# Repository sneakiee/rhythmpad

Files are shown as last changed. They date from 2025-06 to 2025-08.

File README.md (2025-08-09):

# rhythmpad



This was a YSWS project for Hack Club's hackpad for hack club's highway! I got the idea of creating a hackpad for rhythm games, but I also wanted to generalize it more for music, so I decided to make it into a drum-pad by creating square keycaps! The switches are mapped to the numpad from 1-9 and the extra button on the right being 0. This was my first actual hardware project and I hope to build more because it was a frustrating fun (I need to feel more of that.

# Schematic and PCB
pcb schematic
pcb
3dpcb

# CAD
bottomcase
plate
midcase
3d model

# Components
- 10x cherry mx switches
- 10x through-hole 1N4148 diodes
- 6x SK6812 MINI-E LEDs (unfortunately doesn't work with original files, but if SK6812MINI footprint in KiCad is changed, will work!)
- 1x seeeed XIAO RP2040
- 10x custom 3D printed keycaps
- custom 3D printed top case
- custom 3D printed middle case
- custom 3D printed bottom case
- 4x M3x16 Bolt
- 4x M3 Heatset

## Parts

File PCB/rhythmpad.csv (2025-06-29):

Id | Designator | Footprint | Quantity | Designation | Supplier and ref
1 | D16,D15,D14,D13,D11,D12 | LED_SK6812MINI_PLCC4_3.5x3.5mm_P1.75mm | 6 | SK6812MINI
2 | D3,D8,D4,D9,D2,D6,D7,D1,D5,D10 | D_DO-35_SOD27_P7.62mm_Horizontal | 10 | D
3 | SW5,SW10,SW9,SW3,SW1,SW8,SW4,SW7,SW6,SW2 | SW_Cherry_MX_1.00u_PCB | 10 | SW_Push
4 | U1 | XIAO-RP2040-DIP | 1 | XIAO-RP2040-DIP

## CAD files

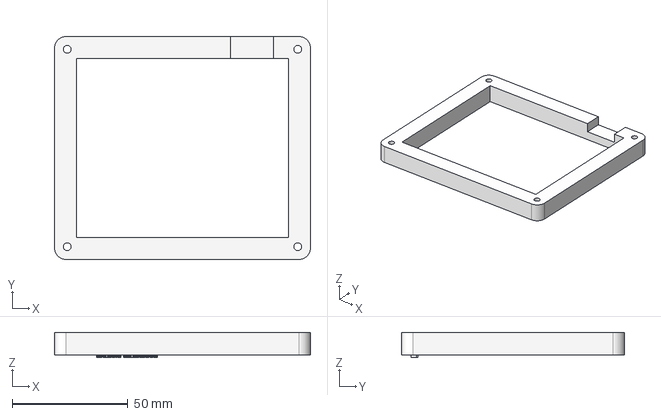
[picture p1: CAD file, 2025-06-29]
production/middle.step
110.5 x 96.2 x 11.0 mm

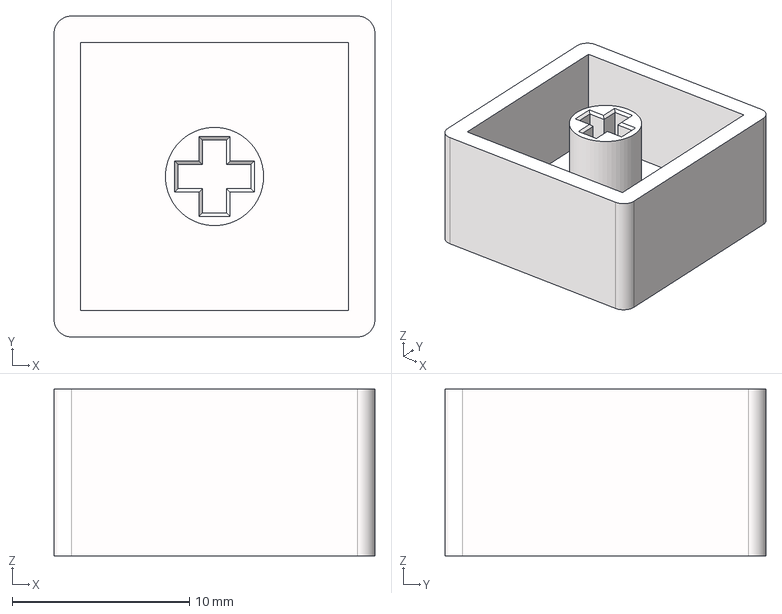
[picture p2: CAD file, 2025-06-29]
production/keycap.step
18.1 x 18.1 x 9.39 mm

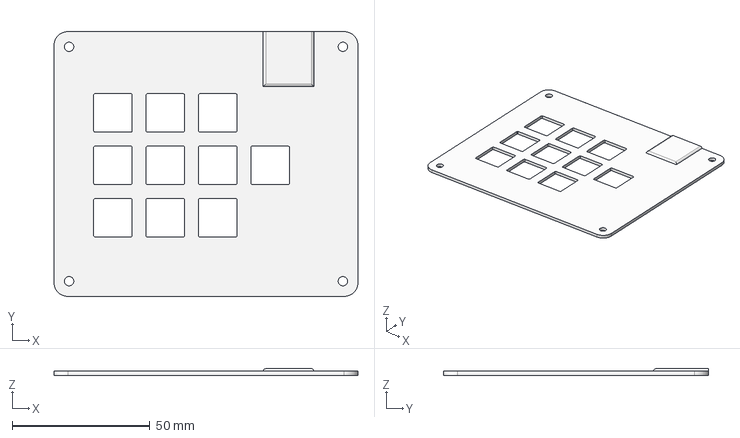
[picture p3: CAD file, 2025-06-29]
production/top.step
110.5 x 96.2 x 2.40 mm

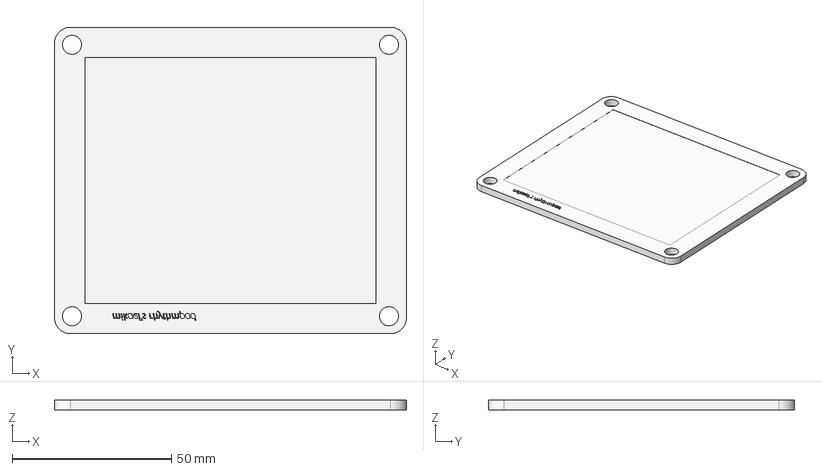
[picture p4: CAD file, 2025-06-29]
production/bottom.step
110.5 x 96.2 x 3.10 mm

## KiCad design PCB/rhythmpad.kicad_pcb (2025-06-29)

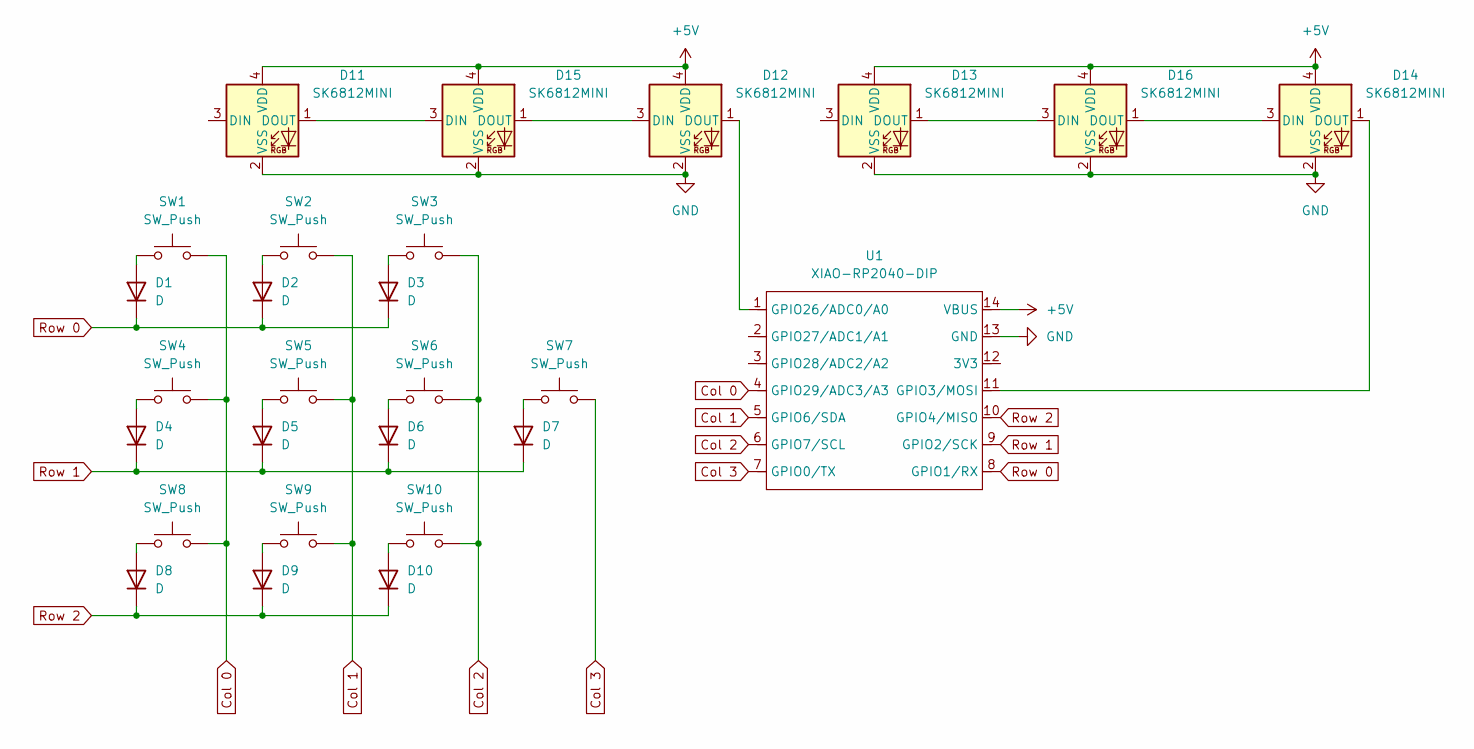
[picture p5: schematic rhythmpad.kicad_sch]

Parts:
D1, D2, D3, D4, D5, D6, D7, D8, D9, D10: D; D_DO-35_SOD27_P7.62mm_Horizontal
D11, D12, D13, D14, D15, D16: SK6812MINI; LED_SK6812MINI_PLCC4_3.5x3.5mm_P1.75mm
SW1, SW2, SW3, SW4, SW5, SW6, SW7, SW8, SW9, SW10: SW_Push; SW_Cherry_MX_1.00u_PCB
U1: XIAO-RP2040-DIP

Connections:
+5V: D11.4 (VDD), D12.4 (VDD), D13.4 (VDD), D14.4 (VDD), D15.4 (VDD), D16.4 (VDD), U1.14 (VBUS)
Col 0: SW1.2, SW4.2, SW8.2, U1.4 (GPIO29/ADC3/A3)
Col 1: SW2.2, SW5.2, SW9.2, U1.5 (GPIO6/SDA)
Col 2: SW3.2, SW6.2, SW10.2, U1.6 (GPIO7/SCL)
Col 3: SW7.2, U1.7 (GPIO0/TX)
GND: D11.2 (VSS), D12.2 (VSS), D13.2 (VSS), D14.2 (VSS), D15.2 (VSS), D16.2 (VSS), U1.13 (GND)
unnamed: D1.2 (A), SW1.1
unnamed: D2.2 (A), SW2.1
unnamed: D3.2 (A), SW3.1
unnamed: D4.2 (A), SW4.1
unnamed: D5.2 (A), SW5.1
unnamed: D6.2 (A), SW6.1
unnamed: D7.2 (A), SW7.1
unnamed: D8.2 (A), SW8.1
unnamed: D9.2 (A), SW9.1
unnamed: D10.2 (A), SW10.1
unnamed: D11.1 (DOUT), D15.3 (DIN)
unnamed: D12.3 (DIN), D15.1 (DOUT)
unnamed: D12.1 (DOUT), U1.1 (GPIO26/ADC0/A0)
unnamed: D13.1 (DOUT), D16.3 (DIN)
unnamed: D14.3 (DIN), D16.1 (DOUT)
unnamed: D14.1 (DOUT), U1.11 (GPIO3/MOSI)
Row 0: D1.1 (K), D2.1 (K), D3.1 (K), U1.8 (GPIO1/RX)
Row 1: D4.1 (K), D5.1 (K), D6.1 (K), D7.1 (K), U1.9 (GPIO2/SCK)
Row 2: D8.1 (K), D9.1 (K), D10.1 (K), U1.10 (GPIO4/MISO)

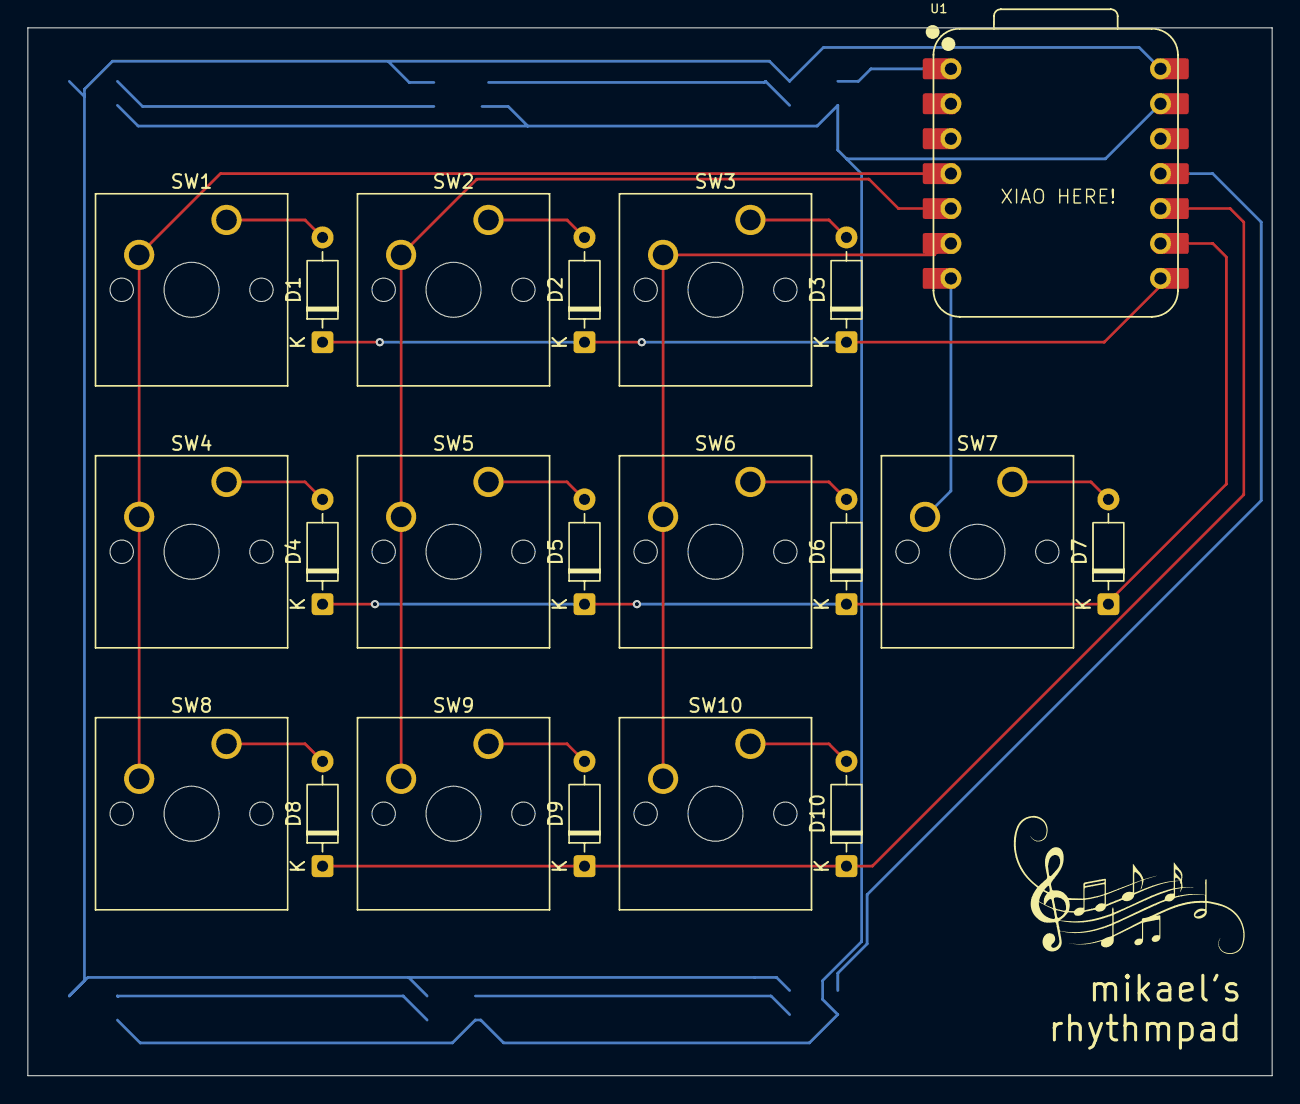
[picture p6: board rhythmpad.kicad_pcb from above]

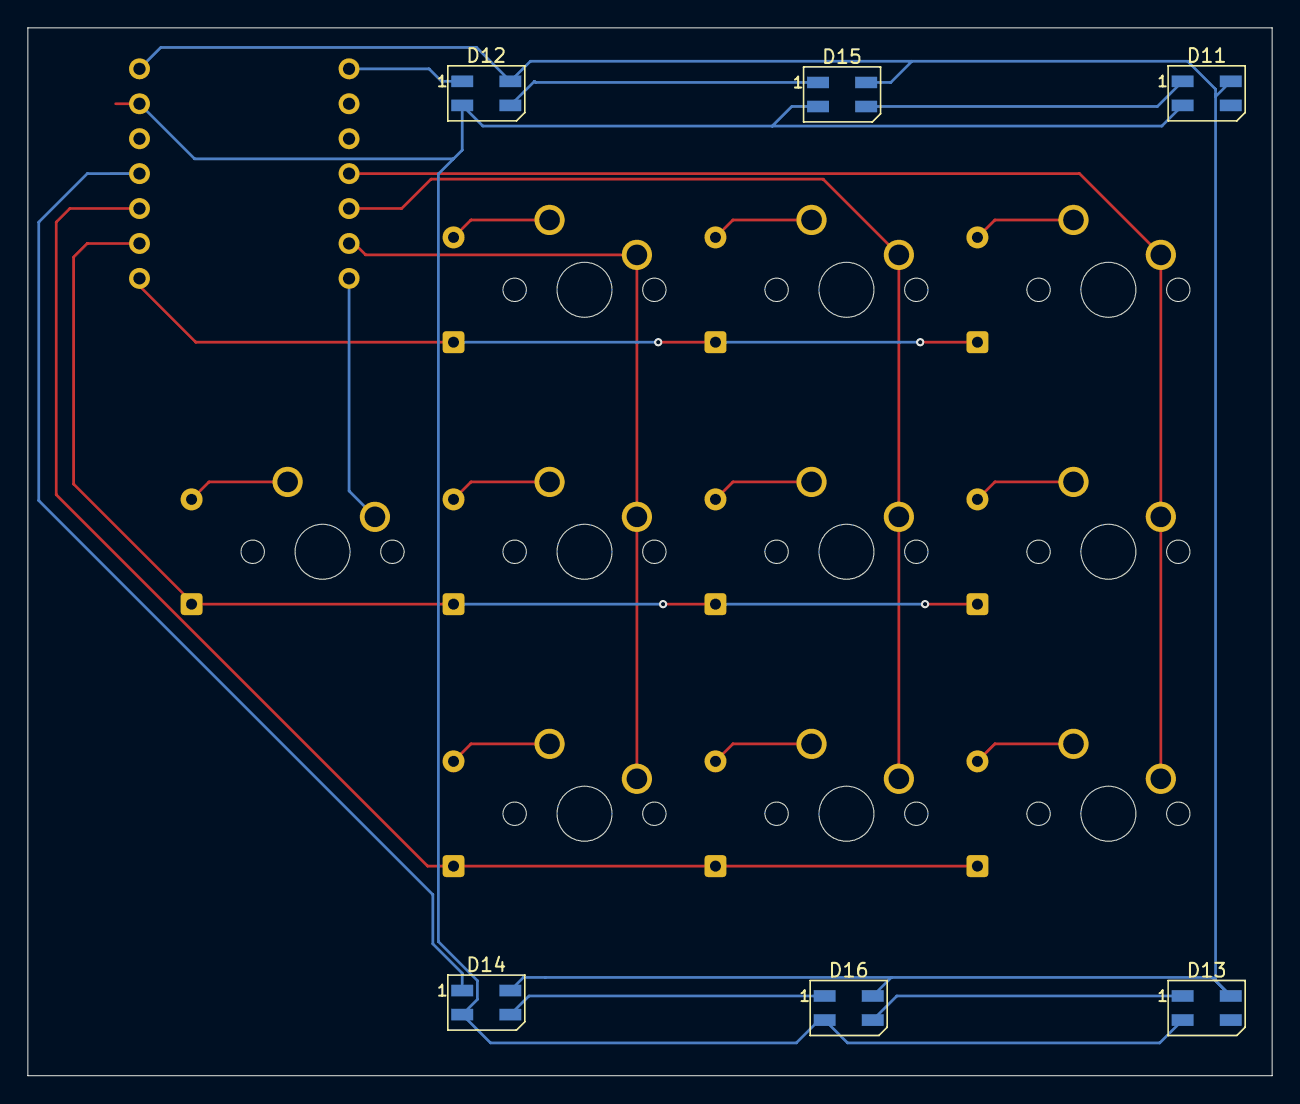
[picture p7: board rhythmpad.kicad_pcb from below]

Board: 2 copper layers, 90.5 x 76.2 mm, 27 parts (6 on the bottom side), 25 nets.

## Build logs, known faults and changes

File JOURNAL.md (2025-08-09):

---
title: "rhythmpad"
author: "Mikael Gomez"
description: "macropad for all rhythm needs (game, drumpad, etc.)"
created_at: "2025-06-11"
---

# June 11th: finished switch matrix & connections 

figured out how to use KiCad! took me a little to understand what was what and a lot of googling to understand PCB structure, but I think I have it down enough LOL

journalentry1

**Total time spent: 2h**

# June 25th: added leds & wired pcb

added some leds and completed the wiring for my pcb :D
i genuinely took so long because it was hard to find a reference and i accidentally had the wrong footprint for my micro controller D:

journalentry2

**Total time spent: 3h**

# June 26th: learning cad :sob:

i wanted to use onshape and ended up having to google too much. lesson learned, be smart and actually look for a tutorial instead of just doing it.
what is wrong wit meee (finishing case incoming)

journalentry3

**Total time spent: 1h**

# June 28th: most productive day!!

locked in and decided to finish everything! i took so long trying to fix problems and never thought of creative ways so i took very very long,
but then i added more leds, created my own keycaps, wrote my firmware, and finished my case! this took too long.... :sob:

3d model

**Total time spent: 5h**

# July 27th-29th: building the thing!

i got all my parts + my soldering iron and was ready to finally build this thing! my main problem was the RP2040 as it was pretty difficult to solder something so small as a beginner hardware maker.. i ended up having to redo with a whole other board, even breaking 2 pins of the xiao in the process... whoops...



its okay though! i somehow desoldered it and learned how to solder decently and then all i needed to do was to solder the LEDS!



i had built my hackpad, and all i really needed to do was change the pins in my firmware! (which took a few minutes but we had it going)



i also recorded some gameplay! https://youtu.be/_harP569IKI

**Total time spent: 2h**

# August 8th: shipping day!

guess what... **unfortunately** the SK6812MINI footprints on KiCad are WRONG!!! (i am a victim...) so unfortunately i am not able to use my LEDS...

i literally spent so long trying to debug my newest firmware just to figure out the footprints are just wrong and i can't solder my LEDs or else the LED will literally just be facing downwards and into the pcb. makes me mad but i still really like how it turned out!




**Total time spent: 2h** (mostly debugging </3)

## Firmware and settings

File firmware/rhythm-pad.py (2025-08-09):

import board

from kmk.kmk_keyboard import KMKKeyboard
from kmk.scanners import DiodeOrientation
from kmk.keys import KC

keyboard = KMKKeyboard()

keyboard.col_pins = [board.A3, board.D4, board.D5, board.D6]
keyboard.row_pins = [board.D7, board.D8, board.D9]
keyboard.diode_orientation = DiodeOrientation.COL2ROW

keyboard.keymap = [
        [
        KC.N7, KC.N8, KC.N9, KC.NO,
        KC.N4, KC.N5, KC.N6, KC.N0,
        KC.N1, KC.N2, KC.N3, KC.NO,
    ]
]

if __name__ == '__main__':
    keyboard.go()

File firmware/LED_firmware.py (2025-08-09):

import board
import neopixel
import time

from kmk.kmk_keyboard import KMKKeyboard
from kmk.scanners import DiodeOrientation
from kmk.keys import KC

keyboard = KMKKeyboard()

keyboard.col_pins = [board.A3, board.D4, board.D5, board.D6]
keyboard.row_pins = [board.D7, board.D8, board.D9]
keyboard.diode_orientation = DiodeOrientation.COL2ROW

LED_TOP_PIN = board.A0
LED_BOTTOM_PIN = board.D10
TOP_LEDS = 3
BOTTOM_LEDS = 3

strip_top = neopixel.NeoPixel(LED_TOP_PIN, TOP_LEDS, brightness=1.0, auto_write=False, pixel_order=(1, 0, 2))
strip_bottom = neopixel.NeoPixel(LED_BOTTOM_PIN, BOTTOM_LEDS, brightness=1.0, auto_write=False, pixel_order=(1, 0, 2))

FIXED_COLOR = (255, 255, 255)
FADE_TIME = 0.5

led_map = {
    0: ([0], []),
    1: ([1], []),
    2: ([2], []),
    3: ([0], [0]),
    4: ([1], [1]),
    5: ([2], [2]),
    6: ([2], [2]),
    7: ([], [0]),
    8: ([], [1]),
    9: ([], [2]),
}

active_keys = {}

def update_leds():
    now = time.monotonic()

    # Clear LEDs
    for i in range(TOP_LEDS):
        strip_top[i] = (0, 0, 0)
    for i in range(BOTTOM_LEDS):
        strip_bottom[i] = (0, 0, 0)

    keys_to_remove = []
    for key_index, press_time in active_keys.items():
        elapsed = now - press_time
        if elapsed >= FADE_TIME:
            keys_to_remove.append(key_index)
            continue

        brightness = 1 - (elapsed / FADE_TIME)
        color = tuple(int(c * brightness) for c in FIXED_COLOR)

        top_idxs, bottom_idxs = led_map.get(key_index, ([], []))
        for i in top_idxs:
            strip_top[i] = color
        for i in bottom_idxs:
            strip_bottom[i] = color

    for key in keys_to_remove:
        del active_keys[key]

    strip_top.show()
    strip_bottom.show()

keyboard.keymap = [
        [
        KC.N7, KC.N8, KC.N9, KC.NO,
        KC.N4, KC.N5, KC.N6, KC.N0,
        KC.N1, KC.N2, KC.N3, KC.NO,
    ]
]

def after_matrix_scan(kbd):
    pressed = kbd.matrix_update.pressed
    if pressed:
        for idx, is_pressed in enumerate(pressed):
            if is_pressed and idx not in active_keys:
                active_keys[idx] = time.monotonic()

    update_leds()

keyboard.after_matrix_scan = after_matrix_scan

if __name__ == '__main__':
    keyboard.go()

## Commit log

2025-06-12 upload kicad files
    [rhythmpad.kicad_pcb, rhythmpad.kicad_sch]
2025-06-26 commit pcb/schematic changes
    [rhythmpad.kicad_pcb, rhythmpad.kicad_sch]
2025-06-26 add library/finish pcb
    [Grove - Vision AI Module V2.kicad_pcb, Grove - Vision AI Module V2.kicad_sch, Grove_Vision_AI_V2_BOM.xlsx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]
2025-06-29 remove library
    [Grove - Vision AI Module V2.kicad_pcb, Grove - Vision AI Module V2.kicad_sch, Grove_Vision_AI_V2_BOM.xlsx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]
2025-06-29 remove rhythmpad
    [rhythmpad.kicad_pcb, rhythmpad.kicad_sch]
2025-06-29 commit PCB/CAD/firmware/production
    [bottom.step, keycap.step, middle.step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]
2025-08-09 add led firmware
    if it did work you would use this firmware
